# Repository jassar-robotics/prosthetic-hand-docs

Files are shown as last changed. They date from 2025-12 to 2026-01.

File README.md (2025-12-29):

# Prosthetic Hand Documentation

This repository serves as the central documentation hub for the Prosthetic Hand Project. It contains design references, mechanical components, and supporting files required for development, assembly, and iteration of the prosthetic hand system.

## Naming Convention

To maintain clarity and consistency across parts and files, the following prefixes are used:

r_ — Right-hand–specific components

l_ — Left-hand–specific components

u_ — Universal components shared between both hands

All files should follow this convention to ensure easy identification and scalability of the project.

## Folder Structure
Finger_Components/

Contains all fine mechanical and structural elements required for individual finger assemblies, including:

Linkages

Joints

etc.

This folder focuses on modular finger design to allow reuse, modification, and rapid prototyping.

## If you want, you can also contribute:

Add a CAD / electronics / firmware section

Introduce versioning and revision tracking

Align it with open-source hardware best practices

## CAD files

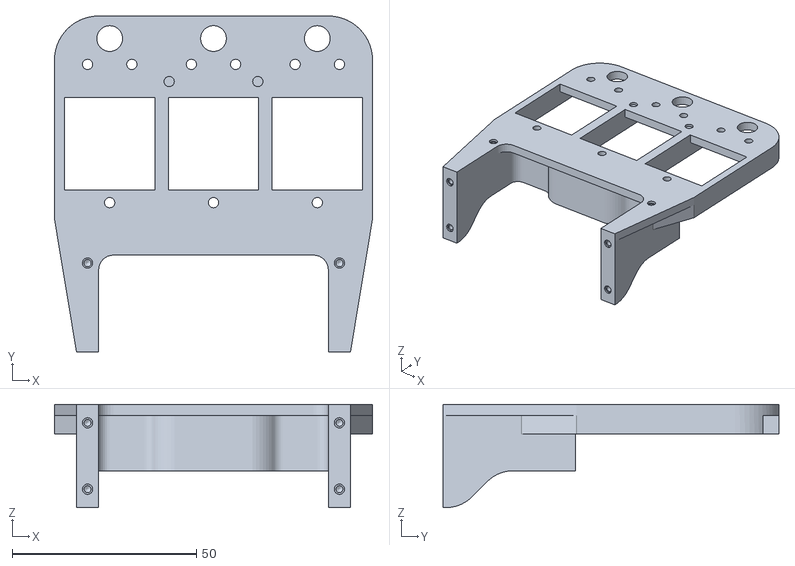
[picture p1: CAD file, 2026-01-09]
cad/farmers-hand-step-file/u_farmers_frame_plate.stl
86.3 x 91.1 x 28.0

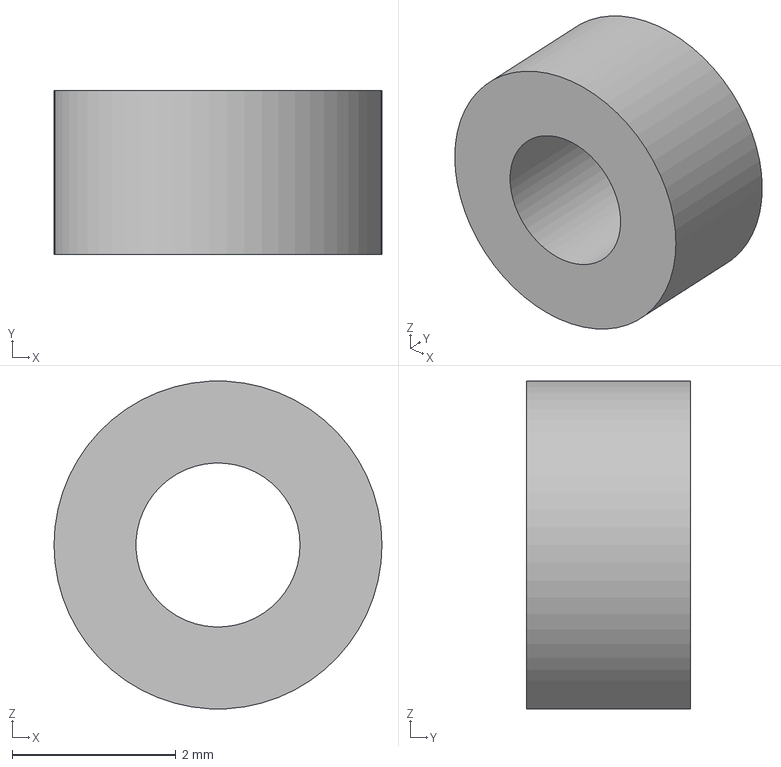
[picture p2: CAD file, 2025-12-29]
cad/step files/finger_components/u_balljoint_rod_spacer.step
4.00 x 2.00 x 3.99 mm

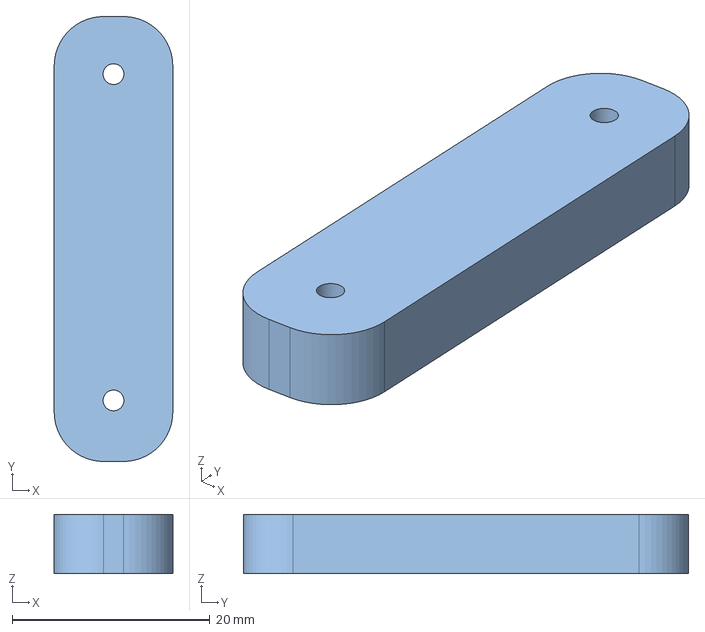
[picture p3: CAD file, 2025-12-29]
cad/step files/tooling_for_assembly/balljoint_rod_length_toolings.step
12.0 x 45.0 x 6.00 mm

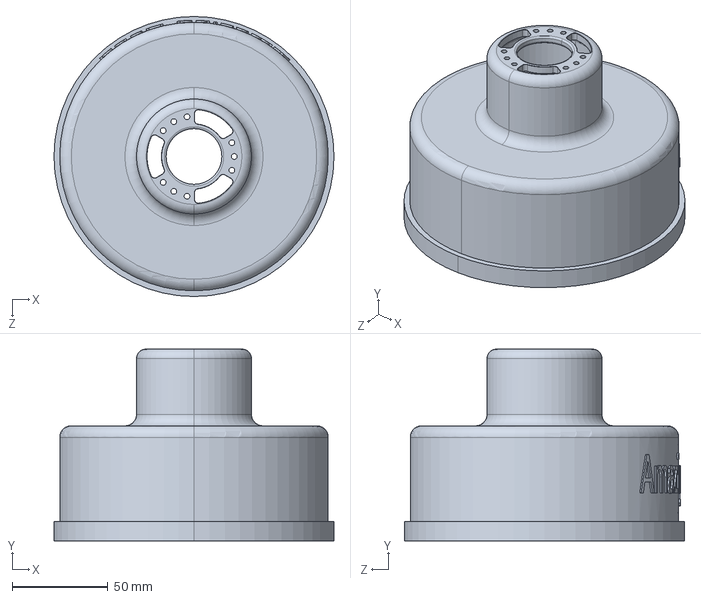
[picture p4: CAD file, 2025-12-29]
cad/step files/u_hand_base.STEP
146.0 x 100.0 x 146.0 mm

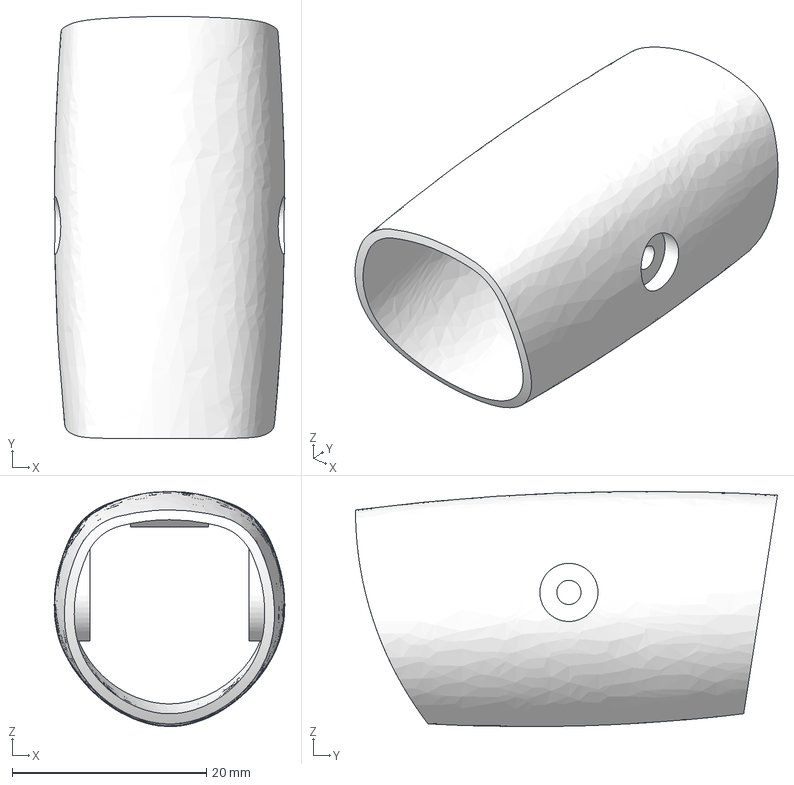
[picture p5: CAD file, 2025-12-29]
cad/step files/finger_components/u_proximal_shell.step
23.8 x 43.5 x 24.2 mm

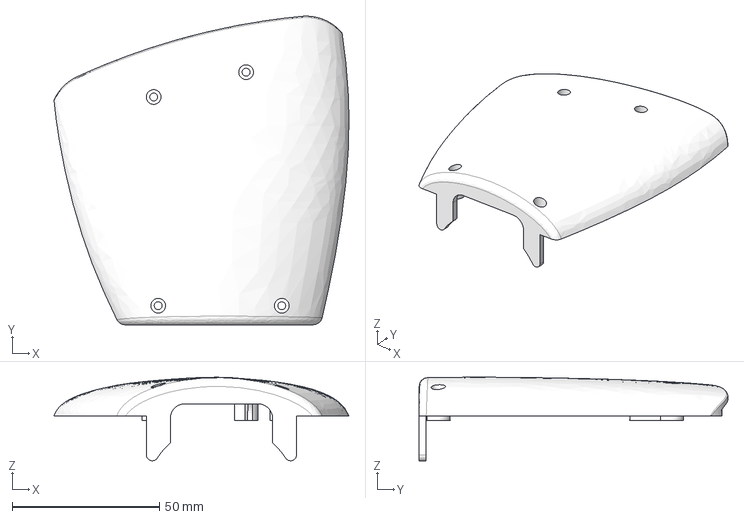
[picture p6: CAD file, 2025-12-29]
cad/step files/l_top_shell.step
100.2 x 104.9 x 28.4 mm

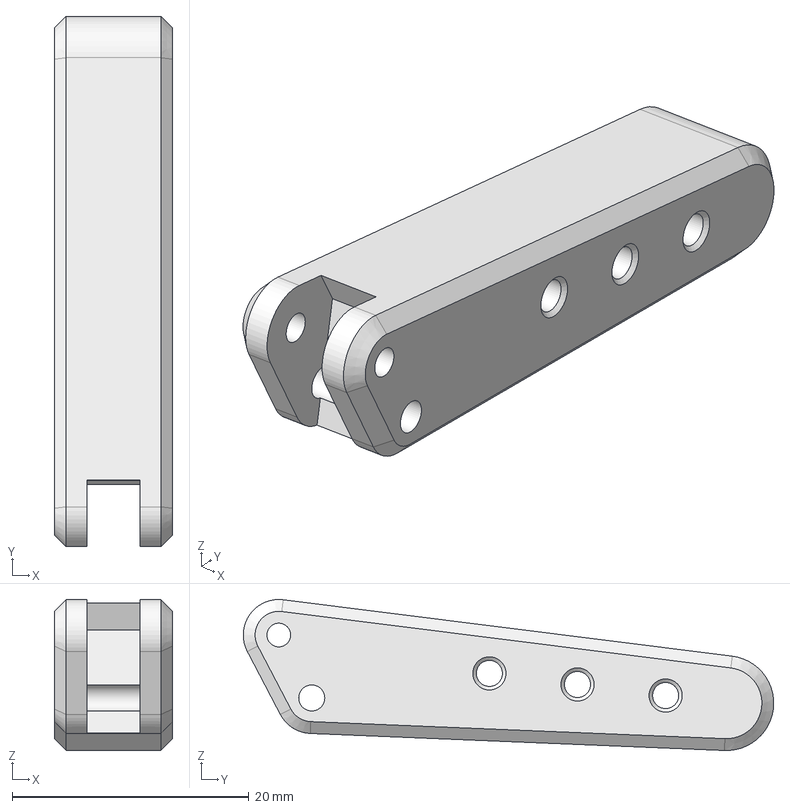
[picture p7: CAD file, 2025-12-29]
cad/step files/finger_components/u_distal.step
10.0 x 44.8 x 12.8 mm

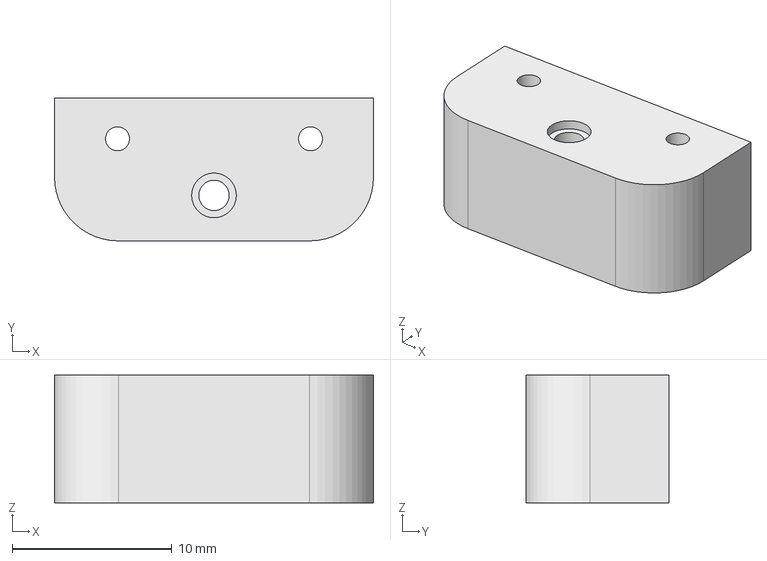
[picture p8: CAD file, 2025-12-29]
cad/step files/u_motor_mount.step
20.0 x 8.95 x 8.00 mm

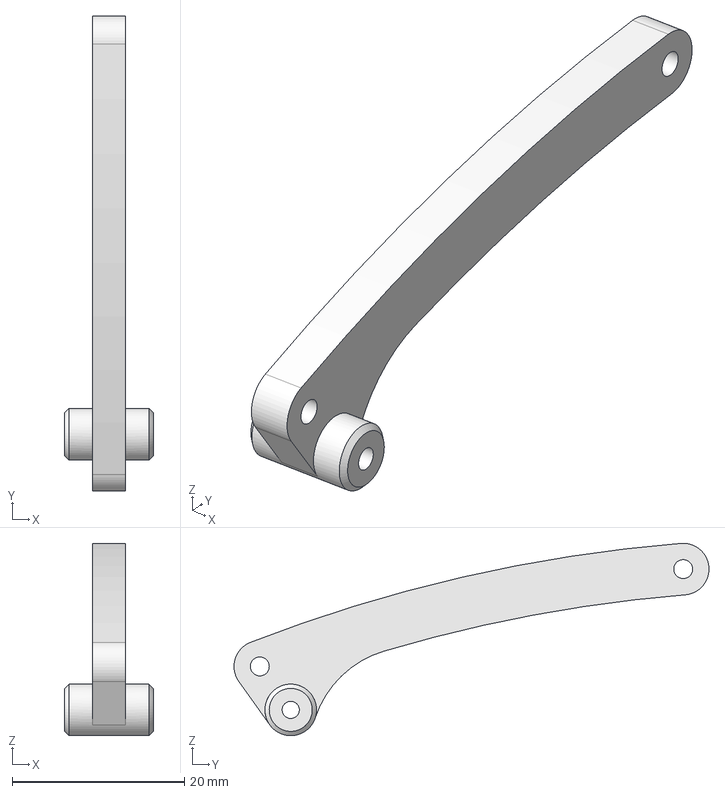
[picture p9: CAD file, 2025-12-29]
cad/step files/finger_components/u_link.step
10.3 x 55.2 x 22.4 mm

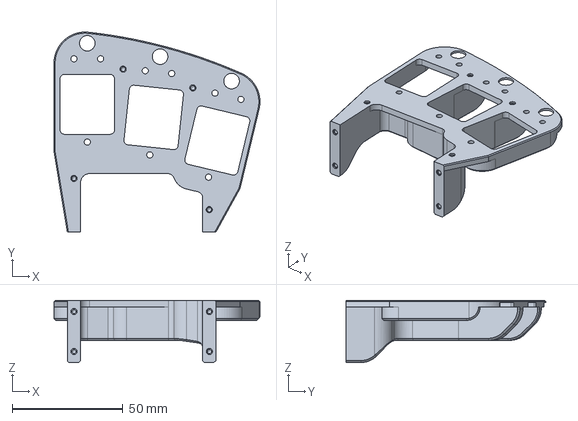
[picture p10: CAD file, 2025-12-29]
cad/step files/r_frame_plate.step
92.8 x 90.1 x 28.0 mm

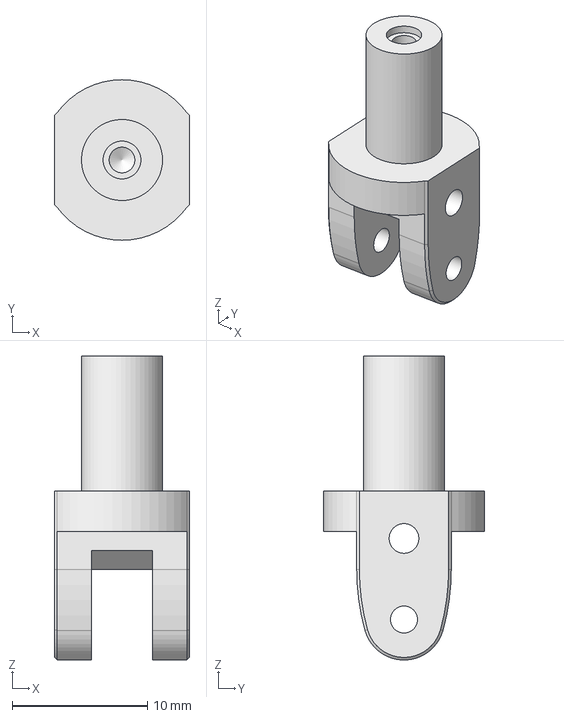
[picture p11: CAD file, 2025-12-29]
cad/step files/finger_components/u_gimbal.step
10.0 x 11.9 x 22.5 mm

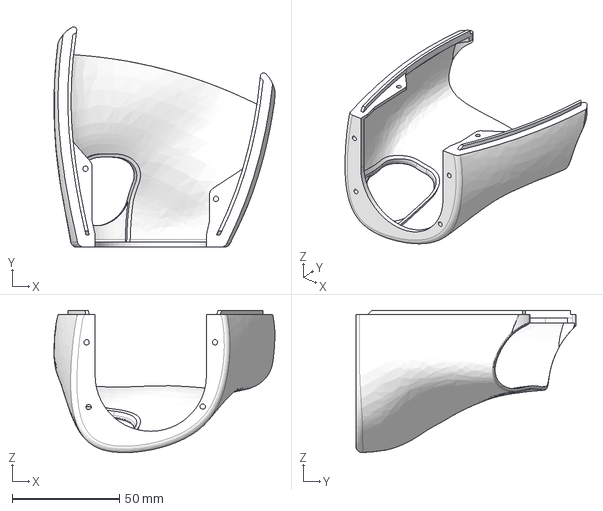
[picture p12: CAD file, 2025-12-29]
cad/step files/r_bottom_shell.step
103.2 x 102.9 x 66.5 mm

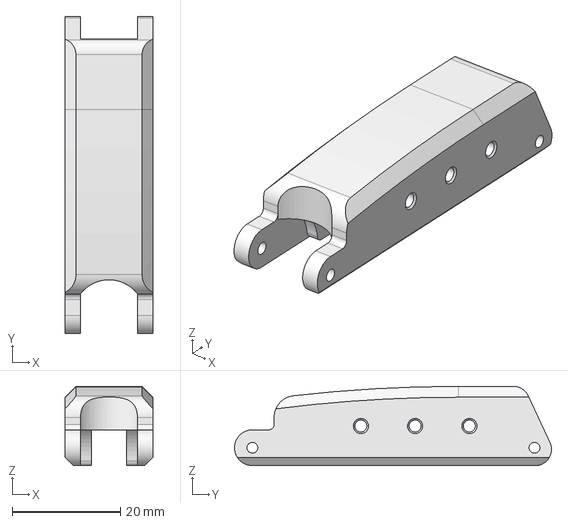
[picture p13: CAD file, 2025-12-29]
cad/step files/finger_components/u_proximal.step
16.2 x 58.4 x 14.6 mm

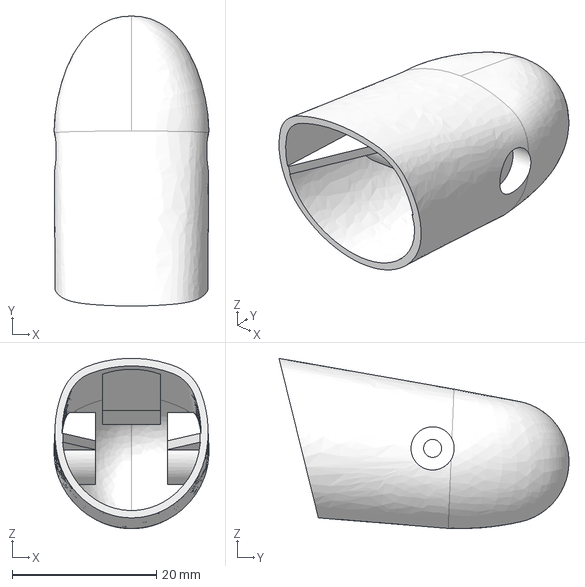
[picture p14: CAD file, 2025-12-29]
cad/step files/finger_components/u_distal_shell.step
21.5 x 40.3 x 23.6 mm

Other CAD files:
cad/step files/l_bottom_shell.step
cad/step files/r_top_shell.step
cad/step files/l_wrist_interface.step
cad/step files/u_ring_motor_mount.step
cad/step files/l_frame_plate.step
cad/step files/r_wrist_interface.step

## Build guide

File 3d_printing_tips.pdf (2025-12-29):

## Finger parts (rigid) :

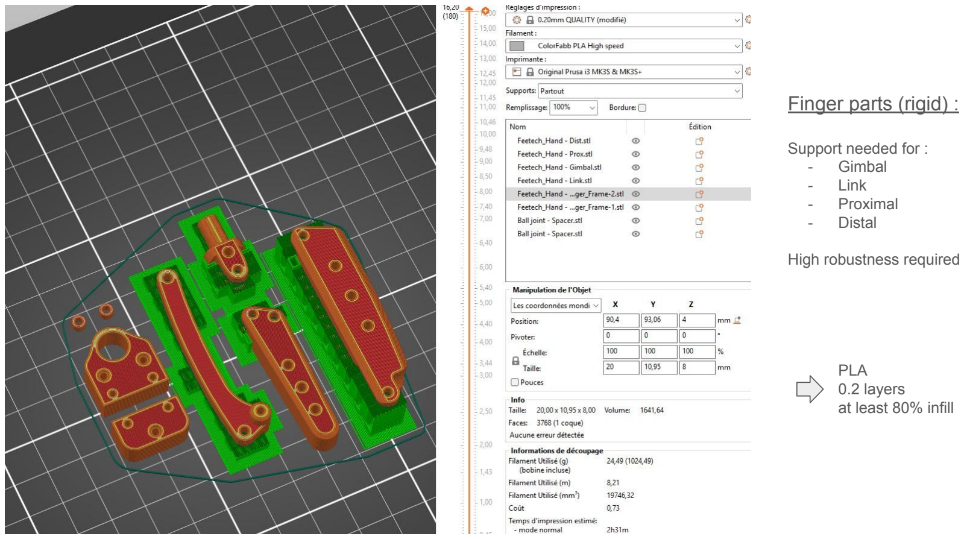
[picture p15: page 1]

Support needed for :
- Gimbal
- Link
- Proximal
- Distal

High robustness required

PLA
0.2 layers
at least 80% infill

## Finger parts (flex) :

No support needed

Flexibility required

Filaflex 82A
0.2 layers
between 40 & 70% infill

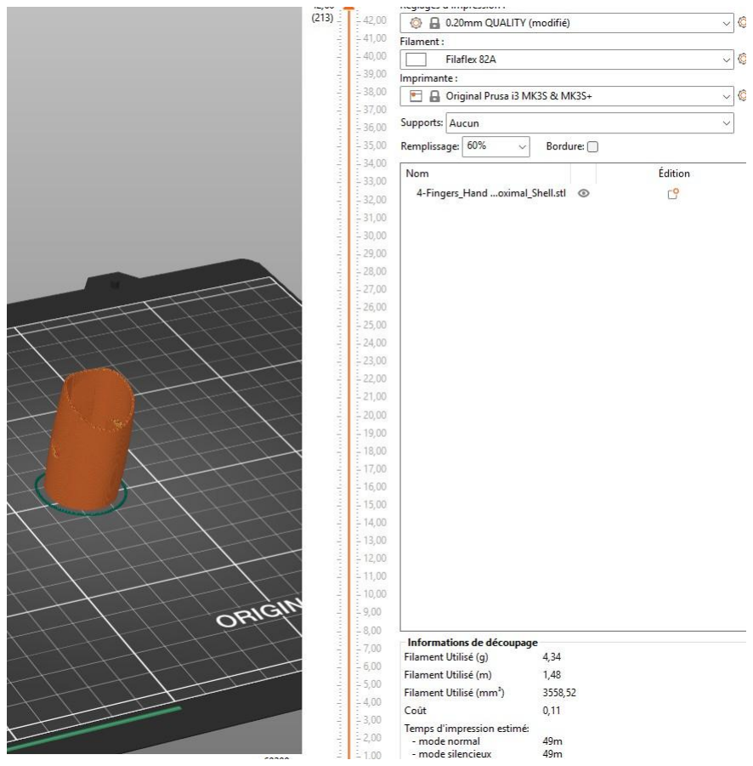
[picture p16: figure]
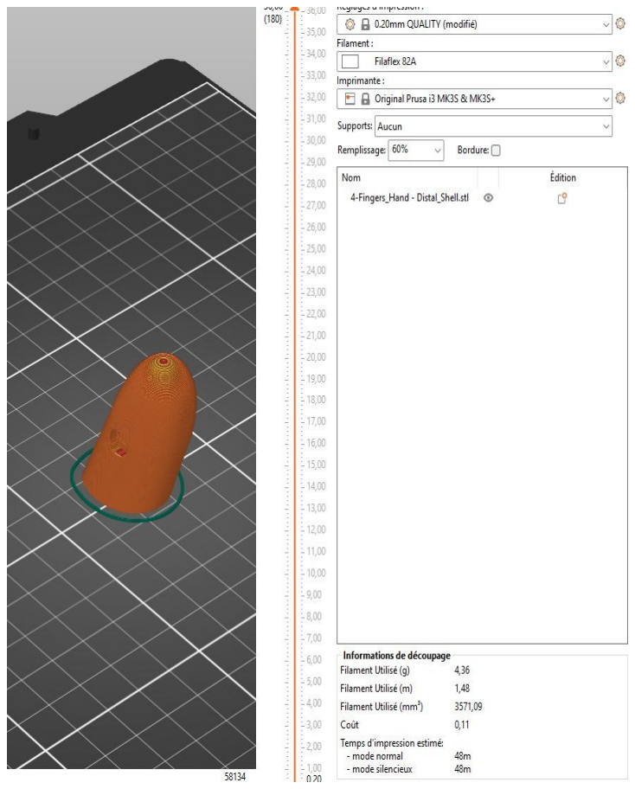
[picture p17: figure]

/!\ Flexible material as Filaflex or TPU is quite hard to print and need a very short distance between extruder and hot end.
Print parameters are specific for each filament and 3D printing machine, so several tests should be needed to obtain perfect result. Be strong ! In general :
- Don’t fill to much the part, it will increase his stiffness
- Don’t use support, it’s often a mess to retire it
- Print parts one by one, to avoid unwanted bridges
- Deactivate “fill gaps” parameters, it could create over thickness randomly
- Try to minimize retractation needed for printing, it could create thin wires that are difficult to remove
Sometimes it’s not possible to respect all these tips, you will have to be patient and precocious to clean flexible parts… Flexible has strong adhesion to printer bed, remember to remove the part quickly after it is finished to prevent bed damages.

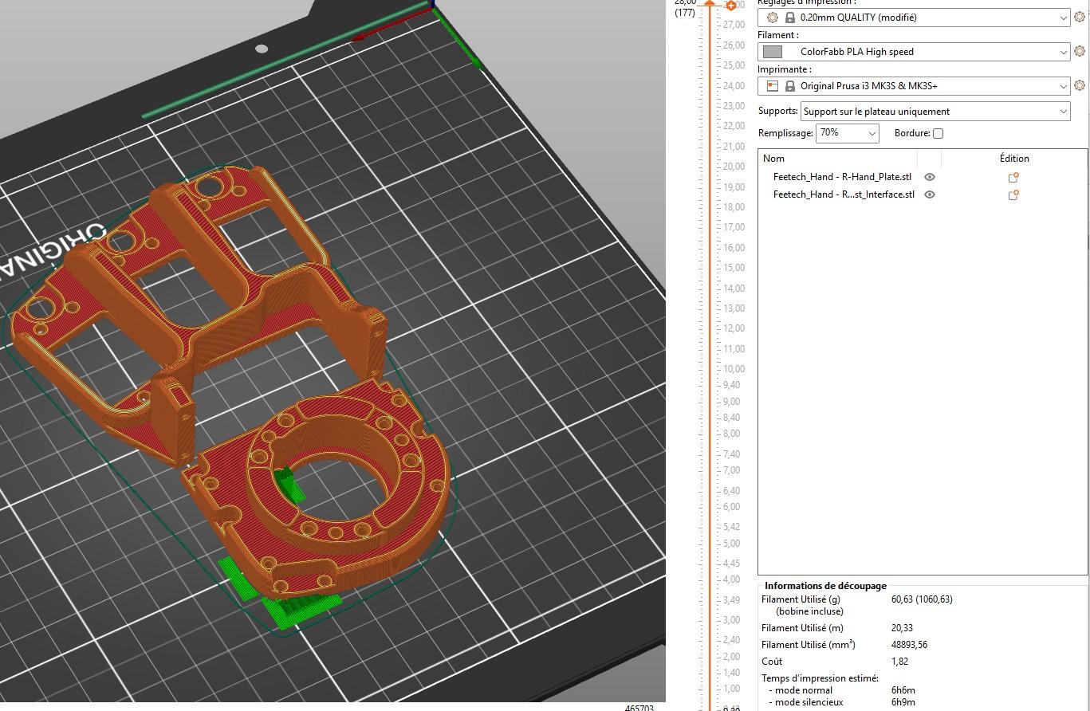
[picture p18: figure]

## Hand parts (rigid) :

Support needed for
- Wrist interface

Robustness required

PLA
0.2 layers
between 60 & 80% infill

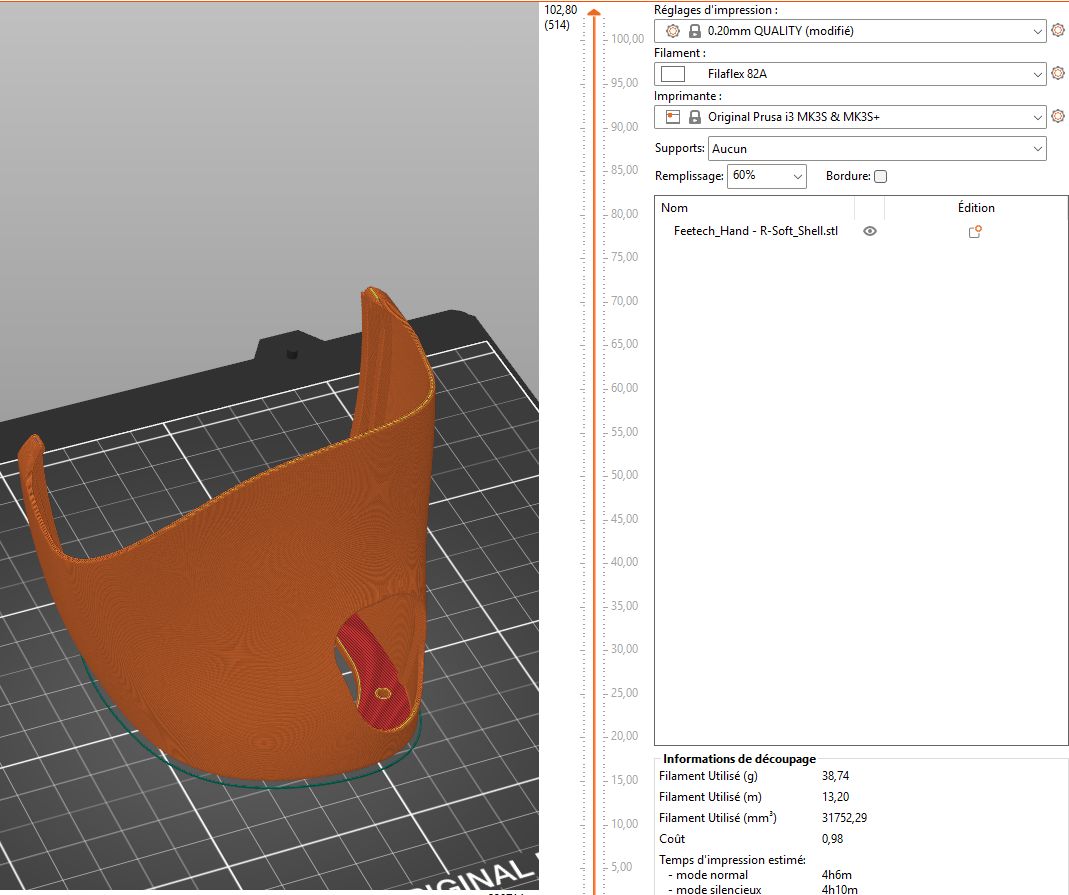
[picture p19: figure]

## Hand shell (flex) :

No support needed

Flexibility required

Filaflex 82A
0.2 layers
between 40 & 70% infill

/!\ Flexible material as Filaflex or TPU is quite hard to print and need a very short distance between extruder and hot end.

Print parameters are specific for each filament and 3D printing machine, so several tests should be needed to obtain perfect result. Be strong !

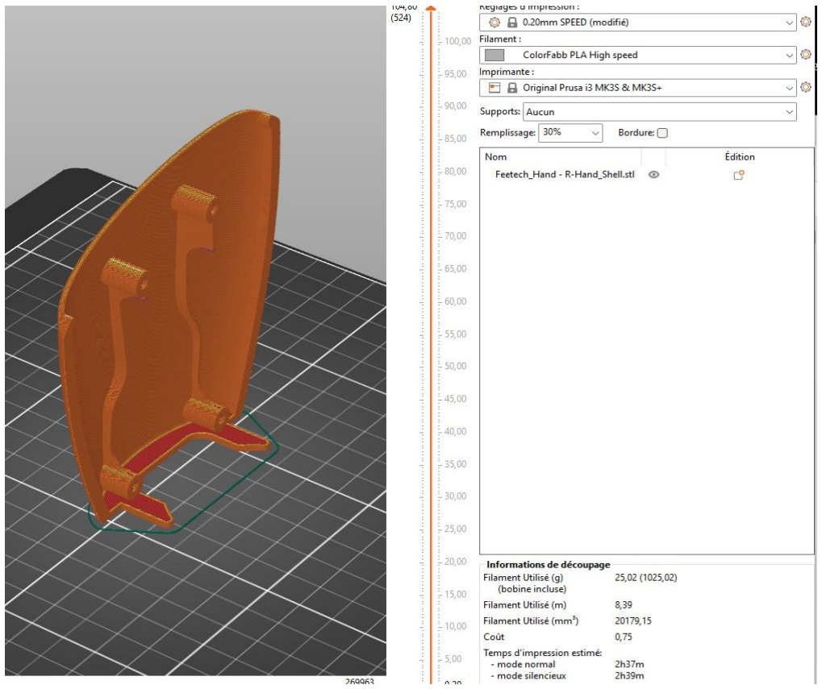
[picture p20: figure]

## Hand shell (rigid) :

No support needed
No robustness required

PLA
0.2 layers
between 20 & 40% infill

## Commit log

2025-12-29 Uploaded V2 Cad files
    [BallJoint_Rod - Length_Toolings.step, BallJoint_Rod - Spacer.step, Finger_Frame-2.step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]
2025-12-29 Add Finger_Frame-1.step file
    [Finger_Frame-1.step]
2025-12-29 Add Distal.step file for hand parts
    [Distal.step]
2025-12-29 Add Distal_Shell.step file
    [Distal_Shell.step]
2025-12-29 Docs: Refactored file names
    [balljoint_rod_length_toolings.step, l_bottom_shell.step, l_frame_plate.step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]
2026-01-09 Added Farmer's Hand Cad files
    It will be a iterations of the original design with more robustness for industrial/field use.
    [u_farmers_frame_plate.stl]
